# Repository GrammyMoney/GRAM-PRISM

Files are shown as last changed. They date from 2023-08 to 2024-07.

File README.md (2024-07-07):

# GRAM PRI$M

# Introduction 
The **PRI$M** is a modular take on the Prism, originally designed by WunWae. It has the standard pinout for firmwares like HayBox and Pico-Rectangle, and is also compatible with more fleshed-out FGC firmwares like GP2040-CE. The key distinctive features between the original Prism and the PRI$M is the USB-C connectivity, and the modular panels that can be replaced and swapped to change the hand layouts without purchasing a whole new controller. With industrial design from GRAM, PCB designed by Quark.Works, this guide goes over a DIY-friendly approach to building and modifying the PRI$M to suit your needs.

**If you would like to support the developers of this project, consider purchasing parts like buttons, PCBs, USB-C to GCC cables, and official GRAM builds at [GRAMCTRL.COM](https://www.gramctrl.com) rather than a fab house.**

IMG_8768 (1)

Included Files
-
Included in this repo is all the files needed to get started with a PRI$M build:
- **PRI$M Frame .stl files**
- **Aluminum Panel** Gerber files *(5 of 'em!)*
- **PCB Gerbers** for multiple hand layouts and a panelized version for the standard layout

Additional Information
-
If you want more info around GRAM builds, both open source and official builds, please join the [GRAM Digital Controllers Discord](https://discord.gg/6TuHw2r2X4) to ask questions and work with the community! I would love to see people creating new interesting designs, and building upon our initial framework.

Thanks & Acknowledgements
-
There are several people who made this project possible, either directly or indirectly.
- [Quark](https://twitter.com/quark_works), who did the PCB design on this and many other GRAM projects.
- [WunWae](https://twitter.com/WuhnWae), who developed the ergonomics and original Prism design. Thank you for your blessing on this crazy project!
- My life and business partner [BRUISES](https://twitter.com/bruisesxo), who has turned GRAM into what it is today, and had incredible patience with me as I toiled away at my computer late into the night designing this thing.

# Ordering & Customization Guide
While most of these files are universal and can be used at any fab house, **JLCPCB** has become the de-facto standard for DIY box manufacturing. This is due to their hyper-affordable pricing and low minimum order quantity.

Bill of Materials
-
Per GRAM PRI$M, you will need (some files can be made using this repository, but I will link to places to purchase them if you would like to avoid MOQs)
- 1 x PRI$M PCB set *(either panelized, or individual PCBs)*
- 1 x set of PRI$M Aluminum Panels
- 20 x [Kailh Choc V1 switches](https://www.moergo.com/products/kailh-choc-v1-key-switches-red-brown-white-pro-red-20-pack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) (Red, Red Pro, and Whites are all great choices)
- 20 x [PG1350 Hotswap Sockets](https://mkultra.click/kailh-hotswap-sockets)
- 20 x Choc v1 keycaps *(I recommend MBK profile)*
- 1 x GRAM PRI$M Frame
- 8 x [M5x0.8 8mm Low-Profile Socket Head Screws](https://www.mcmaster.com/92855A507)
- 2 x [M2.5x0.45 4mm Button Head Screws](https://www.mcmaster.com/catalog/130/3434/97763A412)
- 1 x [4" JST 6-pin Socket to Socket Reversed cable assembly](https://www.digikey.com/en/products/detail/jst-sales-america-inc/A06SR06SR30K102A/9922193)
- 1 x [4" 14-pin FPC Cable](https://www.digikey.com/en/products/detail/molex/0152670295/4427171)

*Optional*
- USB-C to GCC cable for console/adapter play

Tools Needed
-
This guide assumes a level of knowledge on soldering and computer literacy. General tool requirements are:
- Soldering iron
- Solder
- USB-C to USB-A cable
- 3mm hex key/allen wrench
- Pliers
- Patience :)

The PCB
-
***Note: Since the ordering process of the PRI$M is almost identical to the [SLIM](https://github.com/GrammyMoney/GRAM-SLIM), I have used the ordering guide from the SLIM here. You may need to do more repetitions of these steps depending on which PCB you are printing, and you need to do the panel steps for all 5 aluminum panels.***

The PCB Fabrication files should come in the form of a *Gerber ZIP file* and *bom/cpl files* (usually in Excel spreadsheet formats).

Drag them into the "Upload Gerbers" box at JLCPCB and this page will pop up:



Here you can change the color of the PCB. Green is the fastest and cheapest from JLC, but their black PCBs look *siiiiiick*. The only setting I recommend you change is to check "**Yes**" on *Confirm Production file*. This allows for any mistakes to be ironed out by their engineers.

Towards the bottom of the page, you want to turn on the switch for **PCB ASSEMBLY**.



Make sure you are assembling the *Bottom Side* of the PCB, and make sure to set *Confirm Parts Placement* to "**Yes**". None of the advanced options need to be changed.

Upon confirming your PCB Assembly options, you'll be taken to the Assembly wizard. Clicking next will give you a location to upload the *BOM* and *CPL* files (*CPL* is referred to as *Positions* in the GRAM Slim files). Once you click through, you'll be brought to you BOM list.



This will allow you to modify parts if there's any low stock. There's a line at the bottom for CH1-CH21 with some red text. This is for assembling hotswap sockets, which is not recommended for JLC, as you have to preorder them. when you click **next**, continue by clicking *Do not place*.



The wizard looks intimidating, but good news! Since you're confirming part placement, the JLC engineers will fix any errors. Just go ahead and continue.

There you have it! Your PCB is ready to order. As of the time of this writing, a set of 5 assembled boards costs $56.07 before shipping.

The Panels
-
The process of ordering aluminum panels from JLC is similar to the PCB ordering process, but much simpler. Start by dragging the **GRAM Slim Top** Zip file into the JLC upload window. We want an aluminum PCB, 1.6mm. You can choose either white or black coating (white tends to be glossy, black is matte but a fingerprint magnet). 



Under High-spec Options, make sure to remove order number, or else they'll put an ugly serial number on the panel.

Once you save to cart, you'll see this screen:



Here you can add the **GRAM Slim Bottom** Zip file, and it will copy all your settings from the Top panel. Save to cart, and you're ready to check out with your PCBs!

*Note: JLCPCB cannot transact PCB and 3D printing orders together, so place this order, then move on to 3D printing.*

The Frame
-
The frame file is pretty self explanatory. Just go into JLC's 3D printing section, drop the STL file in, and choose your material. I recommend black Resin, but LEDO 6060 is a great, low cost alternative. The only material I recommend against is the textured Nylon options, as the tolerances between the frame and panels are extremely tight, and the texture could interfere with that. make sure the surface finish is set to *sanded*. 

The website will flag some possible errors (Inverted normals, Multi-shells, Possible noise shells) but if you have not modified the .stl file you are good to go. It is also possible that their support contact you about a risk of deformation given the geometry of the workpiece but it is normal and you should reply to the email that you accept the risks.



Need help building your PRI$M? Feel free to join our [Discord](https://discord.gg/gramctrl) for advice from our lovely open source community!

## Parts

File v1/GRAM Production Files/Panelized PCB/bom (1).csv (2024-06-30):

Designator | Footprint | Quantity | Value | LCSC Part #
C1 | 0402 | 1 | 10uF | C15525
C10, C11, C12, C15, C3, C4, C5, C6, C8, C9 | 0402 | 10 | 100nF | C1525
C13, C14 | 0402 | 2 | 22pF | C1555
C16, C17, C2, C7 | 0402 | 4 | 1uF | C52923
C18 | 0603 | 1 | 4.7u | C19666
CH1, CH10, CH11, CH12, CH13, CH14, CH15, CH16, CH17, CH18, CH19, CH2, CH20, CH3, CH4, CH5, CH6, CH7, CH8, CH9 | Kailh_socket_PG1350 | 20 | choc_SW_HS | C5333465
D1 | D_SOD-123 | 1 | Schottky Diode | C8598
D2 | 0805 | 1 | GREEN | C2297
D3 | D_SOD-323 | 1 | Schottky Diode | C191023
F1 | 1206 | 1 | 500 mA | C151162
J2, J5 | TE_1-84953-4_1x14-1MP_P1.0mm_Horizontal | 2 | FFC Connector | C262348
J3, J8 | JST_SH_SM06B-SRSS-TB_1x06-1MP_P1.00mm_Horizontal | 2 | JST Connector | C160405
J6 | TYPE-C_24P_QCHT | 1 | USB C Connector | C456013
R1, R2 | 0603 | 2 | 27 | C25190
R10, R11 | 0603 | 2 | 5.1k | C23186
R3, R8 | 0402 | 2 | 10k | C25744
R4, R5 | 0402 | 2 | 1k | C11702
R6 | 0603 | 1 | 5.6k | C23189
R7 | 0603 | 1 | 10k | C25804
R9 | 0603 | 1 | 1M | C22935
SW1 | SW_SPST_SKQG_WithStem | 1 | Boot | C318884
U1 | RP2040-QFN-56 | 1 | RP2040 | C2040
U2 | SOIC-8_5.23x5.23mm_P1.27mm | 1 | W25Q128JVS | C97521
U3 | SOT-23 | 1 | XC6206 | C5446
U4, U5 | SOT-23-6 | 2 | USBLC6-2SC6 | C7519
Y1 | Crystal_SMD_3225-4Pin_3.2x2.5mm | 1 | 12MHz | C9002

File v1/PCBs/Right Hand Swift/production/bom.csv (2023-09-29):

Designator | Footprint | Quantity | Value | LCSC Part #
CH10, CH11, CH12, CH13, CH14, CH15, CH16, CH17, CH18, CH20, CH8, CH9 | Kailh_socket_PG1350 | 12 | choc_SW_HS | C5333465
J5 | TE_1-84953-4_1x14-1MP_P1.0mm_Horizontal | 1 | FFC Connector | C376047

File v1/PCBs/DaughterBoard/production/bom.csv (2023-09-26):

Designator | Footprint | Quantity | Value | LCSC Part #
C18 | 0603 | 1 | 4.7u | C19666
D3 | D_SOD-323 | 1 | Schottky Diode | C191023
F1 | 1206 | 1 | 500 mA | C70076
J6 | TYPE-C_24P_QCHT | 1 | USB C Connector | C456013
J8 | JST_SH_SM06B-SRSS-TB_1x06-1MP_P1.00mm_Horizontal | 1 | Conn_01x06 | C160405
R10, R11 | 0603 | 2 | 5.1k | C23186
R9 | 0603 | 1 | 1M | C22935
U4, U5 | SOT-23-6 | 2 | USBLC6-2SC6 | C7519

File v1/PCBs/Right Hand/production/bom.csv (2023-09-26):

Designator | Footprint | Quantity | Value | LCSC Part #
CH10, CH11, CH12, CH13, CH14, CH15, CH16, CH17, CH18, CH19, CH20, CH8, CH9 | SW_choc_v1_HS_1u | 13 | choc_SW_HS | C5333465
J5 | TE_1-84953-4_1x14-1MP_P1.0mm_Horizontal | 1 | FFC Connector | C376047

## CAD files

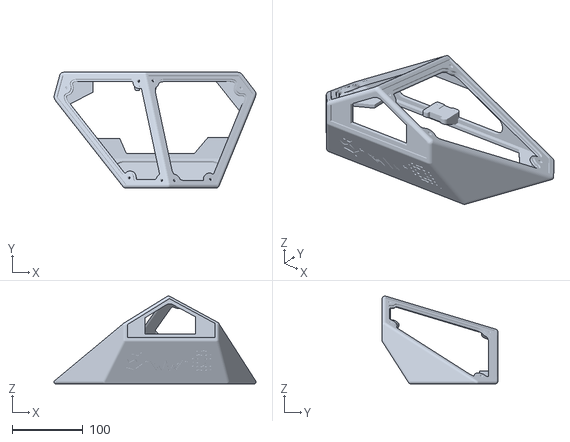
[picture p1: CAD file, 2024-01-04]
v1/GRAM Production Files/gram prism v1 frame.stl
285.0 x 163.6 x 124.0

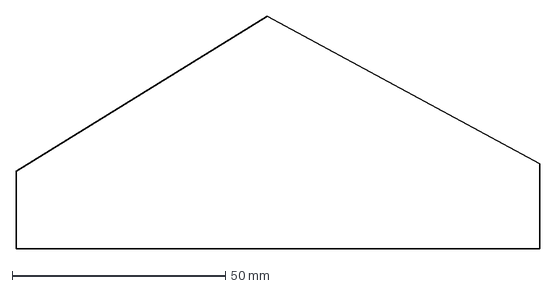
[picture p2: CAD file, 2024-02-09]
v1/outlines/smallest back.dxf
122.6 x 54.6 mm

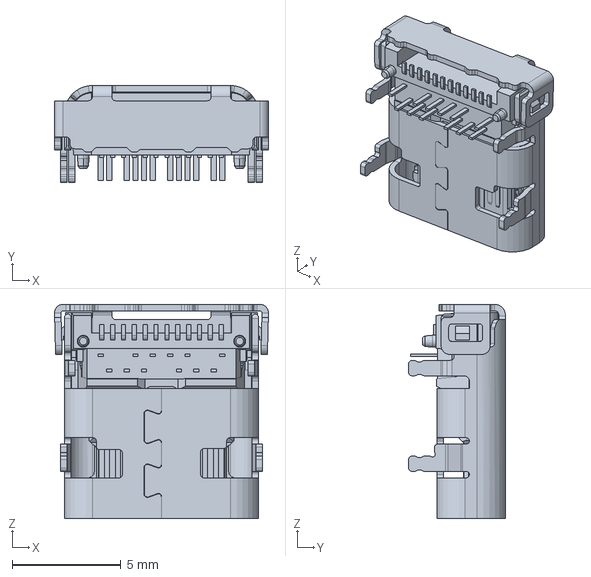
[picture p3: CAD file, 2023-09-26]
v1/PCBs/DaughterBoard/TYPE-C_24P_QCHT.stp
9.85 x 4.46 x 9.87 mm

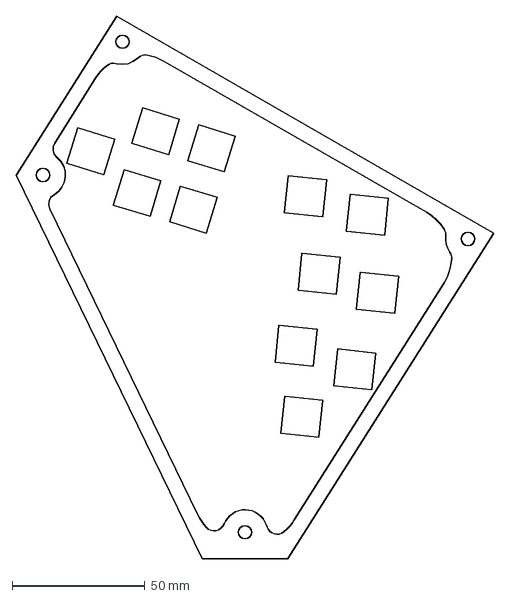
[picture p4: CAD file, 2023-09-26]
v1/user drawings/right pcb user profile (swift style) fixed.dxf
179.8 x 204.4 mm

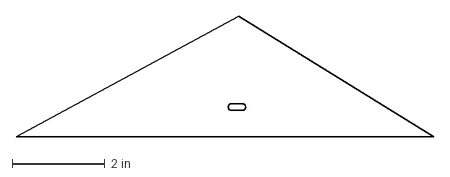
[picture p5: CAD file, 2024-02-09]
v1/outlines/front with port.dxf
8.98 x 2.59 in

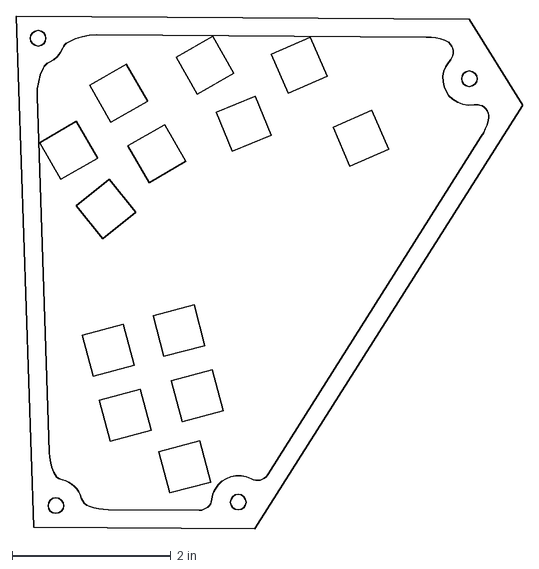
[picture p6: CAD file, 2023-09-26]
v1/user drawings/right_pcb_user_profile_traditional_fixed.dxf
6.37 x 6.45 in

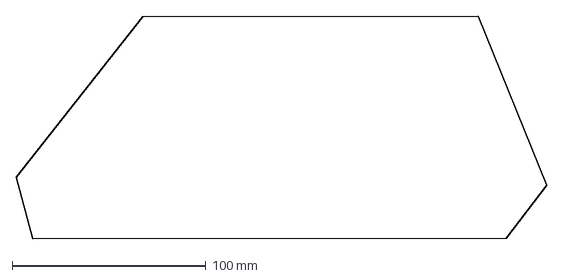
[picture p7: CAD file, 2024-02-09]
v1/outlines/bottom.dxf
273.9 x 114.6 mm

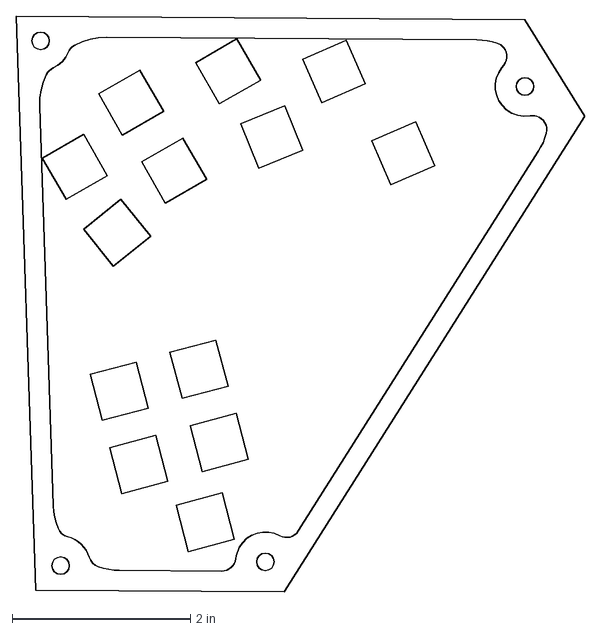
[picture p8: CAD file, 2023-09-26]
v1/user drawings/right pcb user profile (traditional).dxf
6.37 x 6.45 in

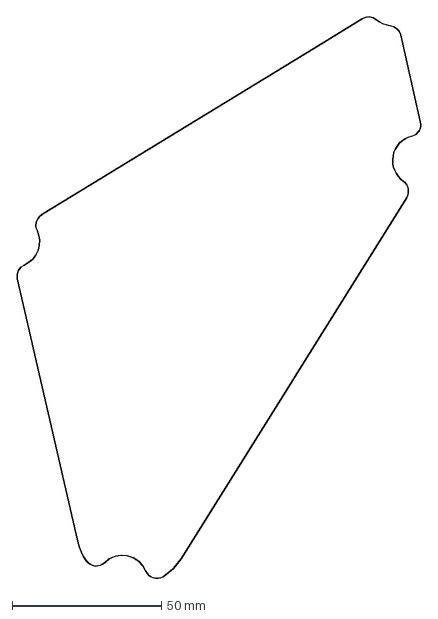
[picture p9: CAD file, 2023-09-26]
v1/outlines/left PCB fixed.dxf
135.8 x 188.4 mm

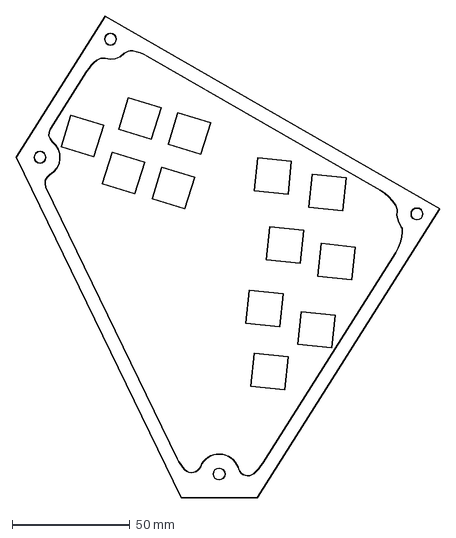
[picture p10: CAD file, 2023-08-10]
v1/user drawings/right pcb user profile (swift style).dxf
179.8 x 204.4 mm

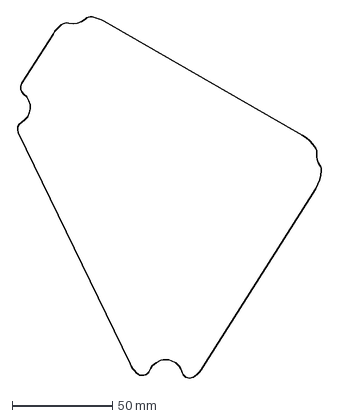
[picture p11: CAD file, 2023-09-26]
v1/outlines/right PCB fixed.dxf
152.4 x 180.9 mm

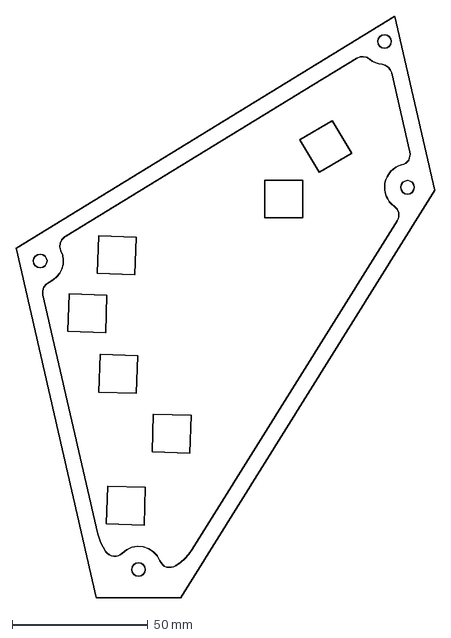
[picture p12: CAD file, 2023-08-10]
v1/user drawings/left pcb user profile.dxf
154.0 x 213.7 mm

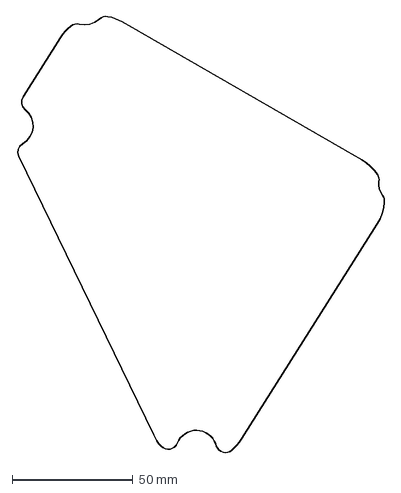
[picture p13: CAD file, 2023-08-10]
v1/outlines/right PCB.dxf
152.4 x 180.9 mm

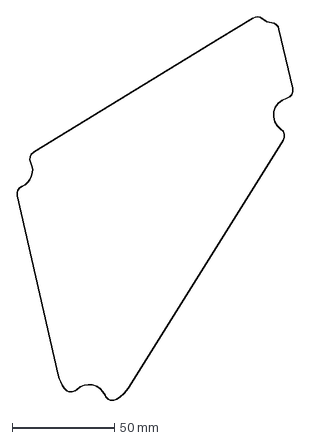
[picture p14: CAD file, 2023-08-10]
v1/outlines/left PCB.dxf
135.8 x 188.4 mm

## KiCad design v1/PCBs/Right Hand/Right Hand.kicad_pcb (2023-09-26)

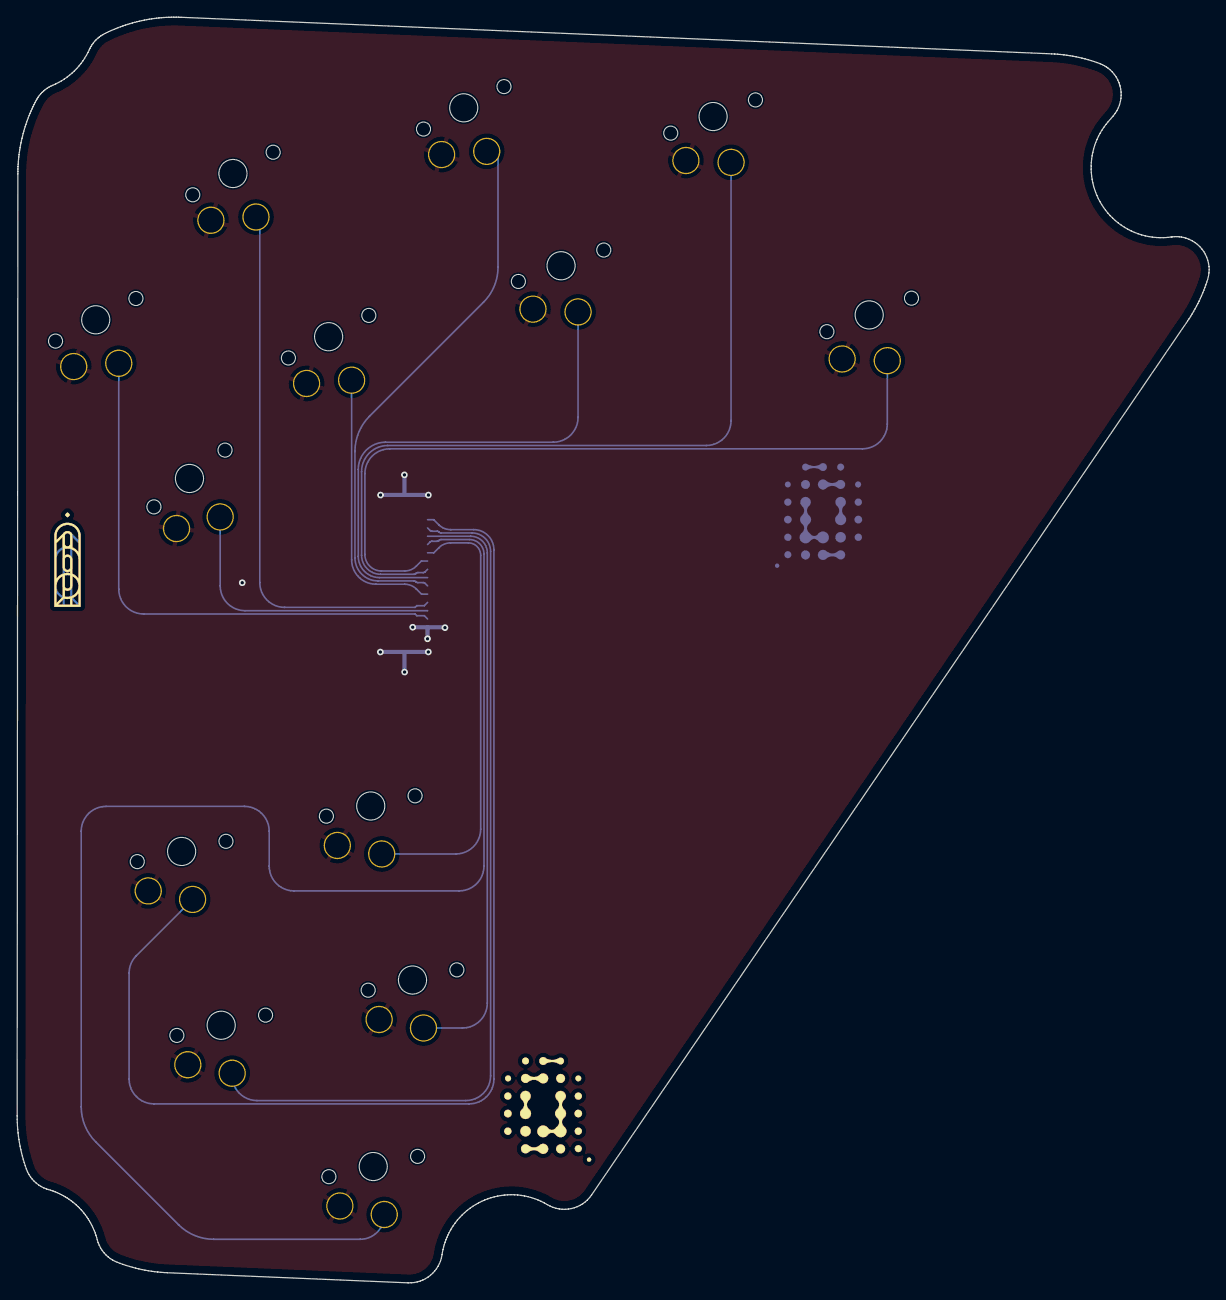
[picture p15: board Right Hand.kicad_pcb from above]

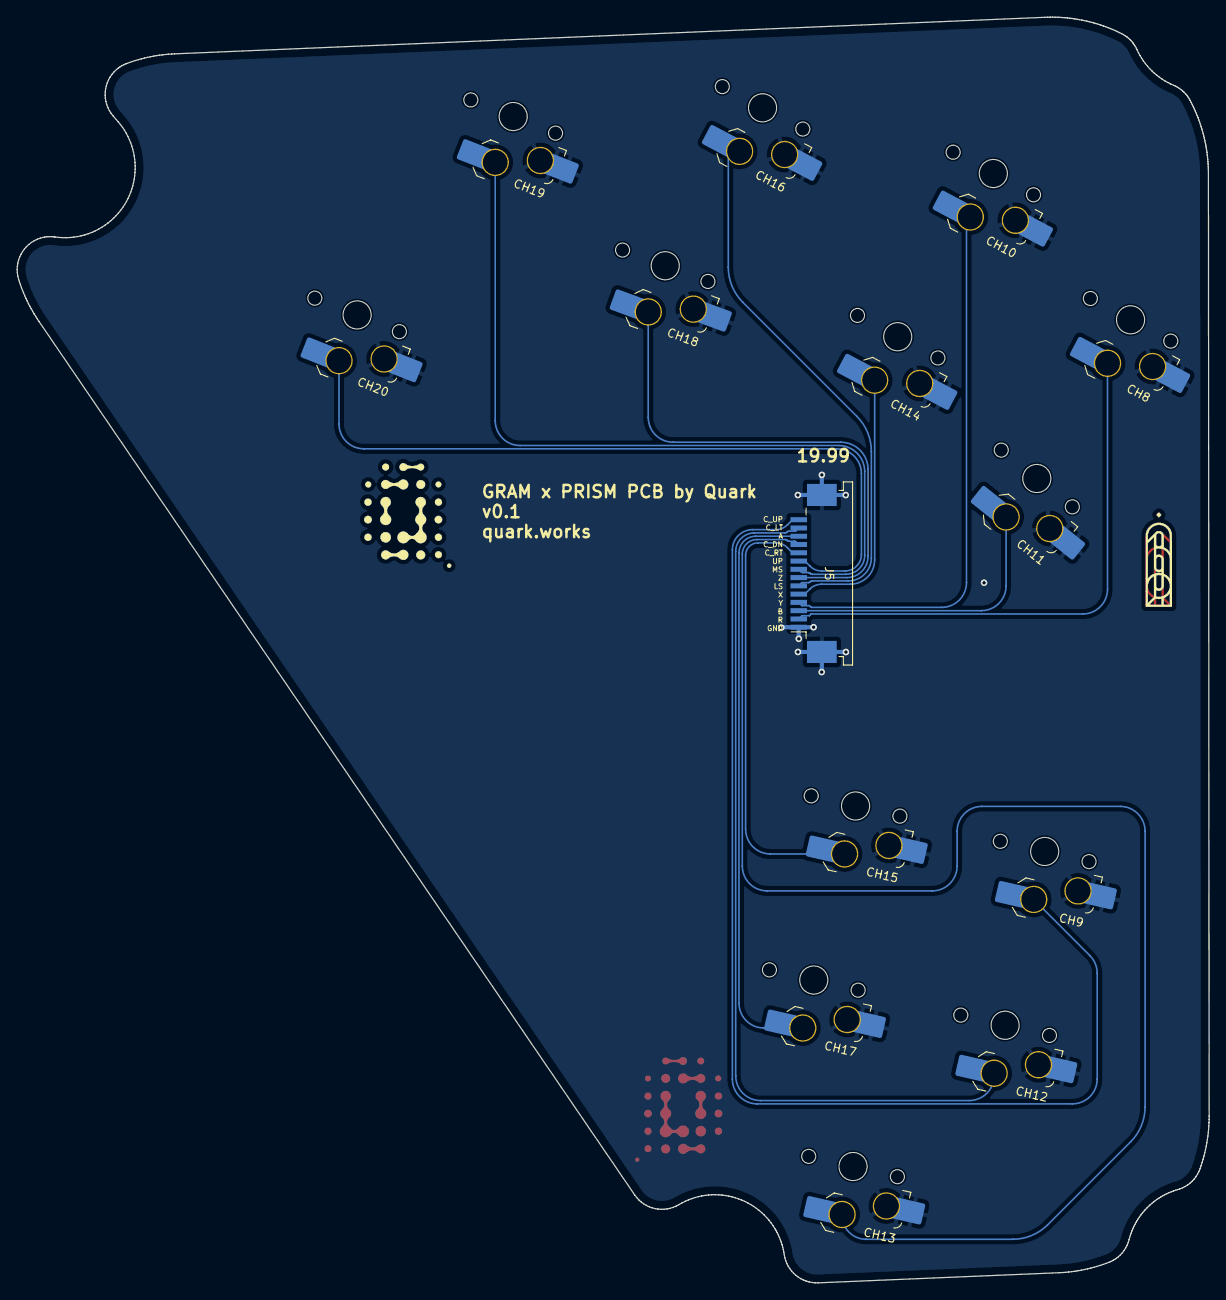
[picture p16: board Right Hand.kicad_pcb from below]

Board: 2 copper layers, 144.1 x 153.0 mm, 18 parts (16 on the bottom side), 14 nets.

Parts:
CH8, CH9, CH10, CH11, CH12, CH13, CH14, CH15, CH16, CH17, CH18, CH19, CH20: choc_SW_HS; SW_choc_v1_HS_1u
H5, H6: qw-logo; qw new logo silk + copper md
H7, H8: 19.99 logo; 1999 logo md
J5: FFC Connector; TE_1-84953-4_1x14-1MP_P1.0mm_Horizontal

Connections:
A: CH17.2, J5.12
B: CH11.2, J5.3
C_DN: CH13.2, J5.11
C_LT: CH12.2, J5.13
C_RT: CH15.2, J5.10
C_UP: CH9.2, J5.14
GND: CH8.1, CH9.1, CH10.1, CH11.1, CH12.1, CH13.1, CH14.1, CH15.1, CH16.1, CH17.1, CH18.1, CH19.1, CH20.1, J5.1, J5.MP (MountPin)
LS: CH16.2, J5.6
MS: CH19.2, J5.8
R: CH8.2, J5.2
UP: CH20.2, J5.9
X: CH14.2, J5.5
Y: CH10.2, J5.4
Z: CH18.2, J5.7

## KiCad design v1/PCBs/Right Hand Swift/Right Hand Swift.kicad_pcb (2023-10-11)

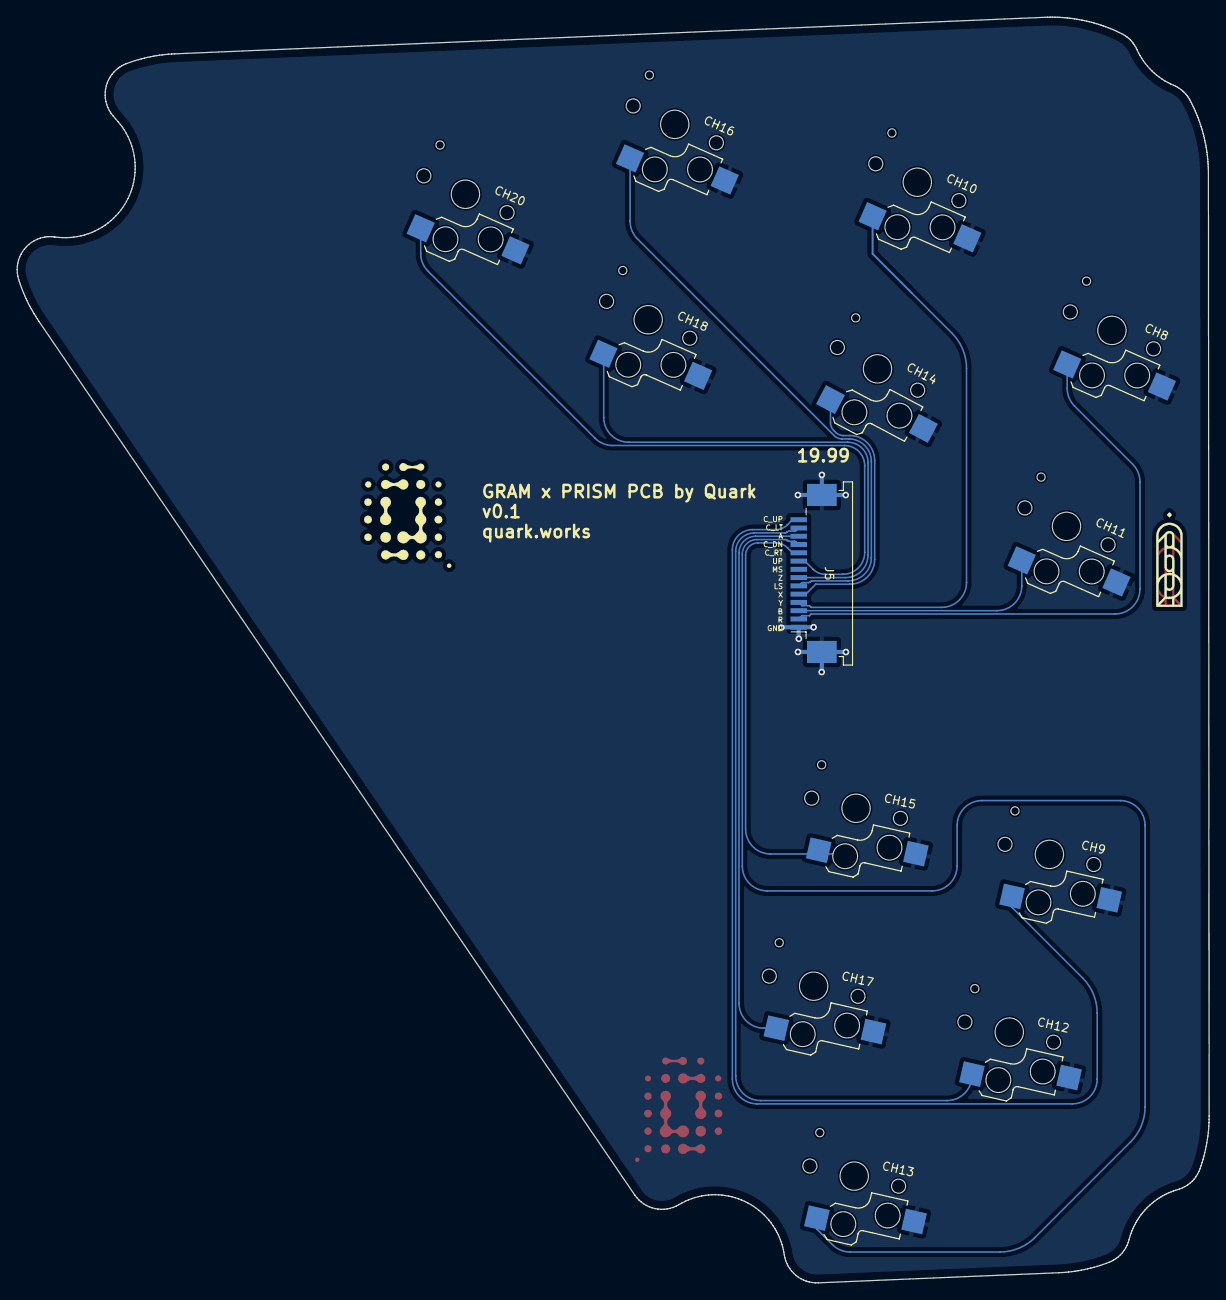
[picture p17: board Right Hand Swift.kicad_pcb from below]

Board: 2 copper layers, 144.1 x 153.0 mm, 17 parts (3 on the bottom side), 13 nets.

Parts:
CH8, CH9, CH10, CH11, CH12, CH13, CH14, CH15, CH16, CH17, CH18, CH20: choc_SW_HS; Kailh_socket_PG1350
H5, H6: qw-logo; qw new logo silk + copper md
H7, H8: 19.99 logo; 1999 logo md
J5: FFC Connector; TE_1-84953-4_1x14-1MP_P1.0mm_Horizontal

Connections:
A: CH17.1, J5.12
B: CH11.1, J5.3
C_DN: CH13.1, J5.11
C_LT: CH12.1, J5.13
C_RT: CH15.1, J5.10
C_UP: CH9.1, J5.14
GND: CH8.2, CH9.2, CH10.2, CH11.2, CH12.2, CH13.2, CH14.2, CH15.2, CH16.2, CH17.2, CH18.2, CH20.2, J5.1, J5.MP (MountPin)
LS: CH16.1, J5.6
R: CH8.1, J5.2
UP: CH20.1, J5.9
X: CH14.1, J5.5
Y: CH10.1, J5.4
Z: CH18.1, J5.7

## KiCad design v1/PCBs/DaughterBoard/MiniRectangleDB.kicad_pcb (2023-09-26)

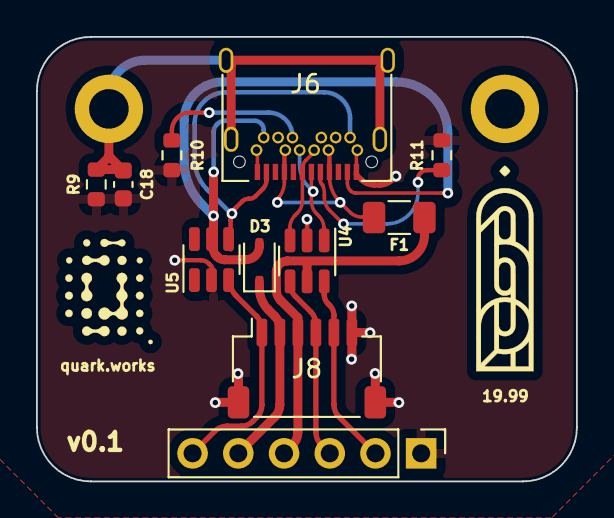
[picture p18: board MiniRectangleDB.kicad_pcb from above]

Board: 2 copper layers, 30.0 x 24.7 mm, 15 parts (0 on the bottom side), 14 nets.

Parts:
C18: 4.7u; C_0603_1608Metric
D3: Schottky Diode; D_SOD-323
F1: 500 mA; Fuse_1206_3216Metric
H9: MountingHole_Pad; MountingHole_2.2mm_M2_DIN965_Pad
H10: MountingHole; MountingHole_2.2mm_M2_DIN965_Pad
H11: qw logo; qw new logo silk + copper sm
H12: 1999 logo; 1999 logo md
J6: USB C Connector; TYPE-C_24P_QCHT
J7: Conn_01x06; PinHeader_1x06_P2.54mm_Vertical
J8: Conn_01x06; JST_SH_SM06B-SRSS-TB_1x06-1MP_P1.00mm_Horizontal
R9: 1M; R_0603_1608Metric
R10, R11: 5.1k; R_0603_1608Metric
U4, U5: USBLC6-2SC6; SOT-23-6

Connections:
3vCable: D3.2 (A), J6.A2 (TX1+), J6.B2 (TX2+), U5.5 (VBUS)
3vDiode: D3.1 (K), J7.5, J8.2
+5V: F1.2, J7.4, J8.3, U4.5 (VBUS)
D+: J7.2, J8.5, U4.6 (I/O1)
D-: J7.3, J8.4, U4.4 (I/O2)
DATA: J7.6, J8.1, U5.3 (I/O2)
DATABUS: J6.A11 (RX2+), J6.B11 (RX1+), U5.4 (I/O2)
DBUS+: J6.A6 (D+), J6.B6 (D+), U4.1 (I/O1)
DBUS-: J6.A7 (D-), J6.B7 (D-), U4.3 (I/O2)
GND: C18.2, J6.A1 (GND), J6.A12 (GND), J6.B1 (GND), J6.B12 (GND), J7.1, J8.6, R9.1, R10.1, R11.2, U4.2 (GND), U5.2 (GND)
unnamed: F1.1, J6.A4 (VBUS), J6.A9 (VBUS), J6.B4 (VBUS), J6.B9 (VBUS)
unnamed: J6.A5 (CC1), R11.1
unnamed: J6.B5 (CC2), R10.2
unnamed: C18.1, H9.1, J6.S1 (SHIELD), R9.2

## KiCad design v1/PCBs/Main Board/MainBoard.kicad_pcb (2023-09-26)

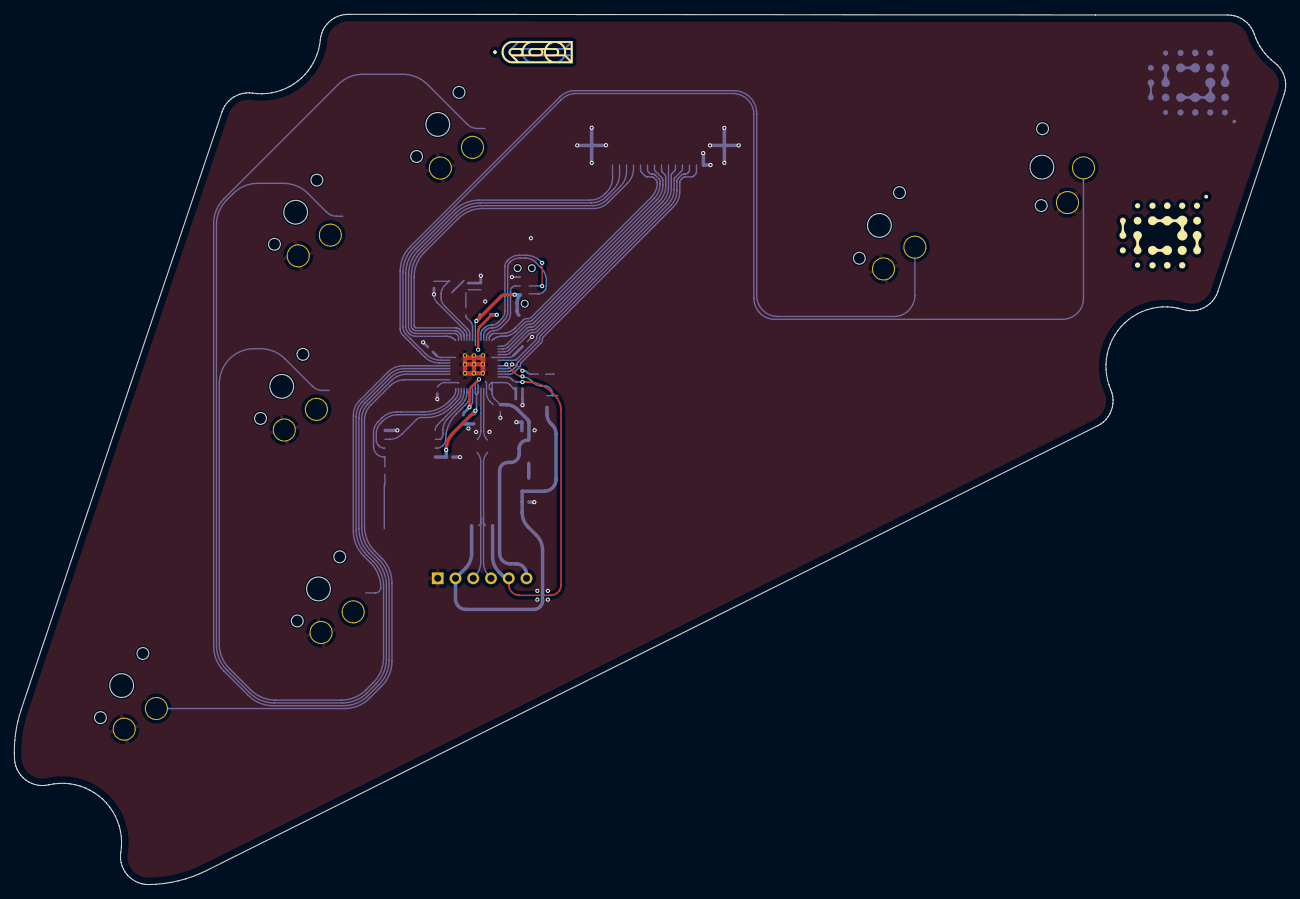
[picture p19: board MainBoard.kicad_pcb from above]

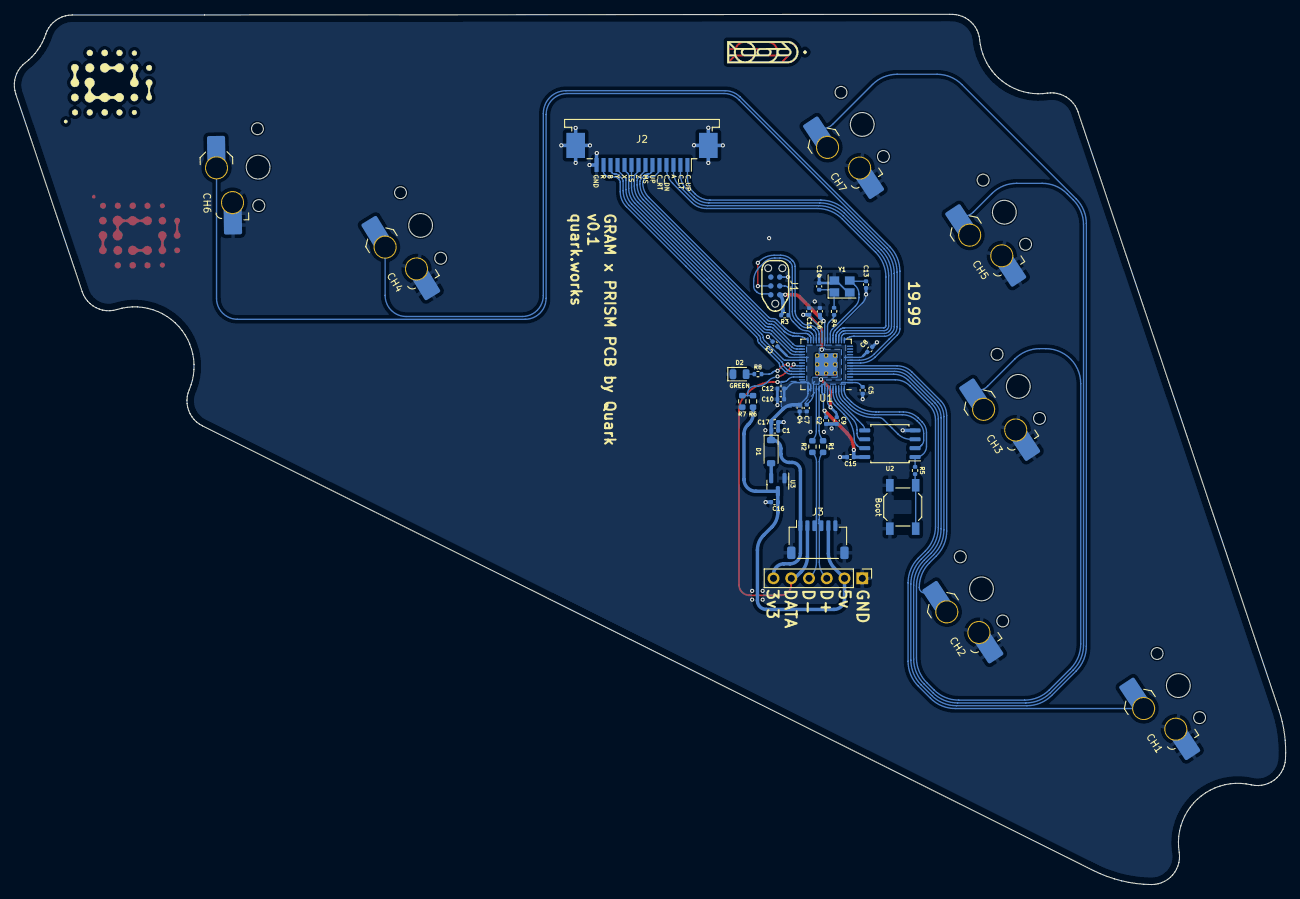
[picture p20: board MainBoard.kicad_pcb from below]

Board: 2 copper layers, 181.9 x 124.5 mm, 47 parts (45 on the bottom side), 46 nets.

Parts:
C1: 10uF; C_0402_1005Metric
C2, C7, C16, C17: 1uF; C_0402_1005Metric
C3, C4, C5, C6, C8, C9, C10, C11, C12, C15: 100nF; C_0402_1005Metric
C13, C14: 22pF; C_0402_1005Metric
CH1, CH2, CH3, CH4, CH5, CH6, CH7: choc_SW_HS; SW_choc_v1_HS_1u
D1: Schottky Diode; D_SOD-123
D2: GREEN; LED_0805_2012Metric
H1, H2: qw-logo; qw new logo silk + copper md
H3, H4: 19.99 logo; 1999 logo md
J1: JTAG_TC2030; CON_TC2030_outlined
J2: FFC Connector; TE_1-84953-4_1x14-1MP_P1.0mm_Horizontal
J3: JST Connector; JST_SH_SM06B-SRSS-TB_1x06-1MP_P1.00mm_Horizontal
J4: DuPont Connector; PinHeader_1x06_P2.54mm_Vertical
R1, R2: 27; R_0603_1608Metric
R3, R8: 10k; R_0402_1005Metric
R4, R5: 1k; R_0402_1005Metric
R6: 5.6k; R_0603_1608Metric
R7: 10k; R_0603_1608Metric
SW1: Boot; SW_SPST_SKQG_WithStem
U1: RP2040; RP2040-QFN-56
U2: W25Q128JVS; SOIC-8_5.23x5.23mm_P1.27mm
U3: XC6206; SOT-23
Y1: 12MHz; Crystal_SMD_3225-4Pin_3.2x2.5mm

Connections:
+1V1: C7.1, C9.1, C11.1, U1.23 (DVDD), U1.45 (VREG_VOUT), U1.50 (DVDD)
+3V3: C1.1, C2.1, C3.1, C4.1, C5.1, C6.1, C8.1, C10.1, C12.1, C15.1, C17.2, D1.1 (K), J1.1 (VCC), J3.1, J4.6, R3.1, U1.1 (IOVDD), U1.10 (IOVDD), U1.22 (IOVDD), U1.33 (IOVDD), U1.42 (IOVDD), U1.43 (ADC_AVDD), U1.44 (VREG_VIN), U1.48 (USB_VDD), U1.49 (IOVDD), U2.8 (VCC)
+5V: C16.2, J3.5, J4.2, R6.1, U3.3 (VI)
/D_+: R1.2, U1.47 (D+)
/D_-: R2.2, U1.46 (D-)
/XTAL_O: C14.2, R4.1, Y1.1
/~USB_BOOT: R5.1, SW1.2
A: J2.3, U1.17 (GPIO14)
B: J2.12, U1.38 (GPIO26/ADC0)
CS: R5.2, U1.56 (QSPI_SS_N), U2.1 (~CS)
C_DN: J2.4, U1.18 (GPIO15)
C_LT: J2.2, U1.16 (GPIO13)
C_RT: J2.5, U1.27 (GPIO16)
C_UP: J2.1, U1.15 (GPIO12)
D+: J3.4, J4.3, R1.1
D-: J3.3, J4.4, R2.1
DATA: J3.2, J4.5, U1.40 (GPIO28/ADC2)
DOWN: CH5.2, U1.5 (GPIO3)
GND: C1.2, C2.2, C3.2, C4.2, C5.2, C6.2, C7.2, C8.2, C9.2, C10.2, C11.2, C12.2, C13.1, C14.1, C15.2, C16.1, C17.1, CH1.1, CH2.1, CH3.1, CH4.1, CH5.1, CH6.1, CH7.1, D2.1 (K), J1.5 (GND), J2.14, J2.MP (MountPin), J3.6, J3.MP (MountPin), J4.1, R7.2, SW1.1, U1.19 (TESTEN), U1.57 (GND), U2.4 (GND), U3.1 (GND), Y1.2, Y1.4
L: CH2.2, U1.7 (GPIO5)
LEFT: CH3.2, U1.6 (GPIO4)
LS: J2.9, U1.31 (GPIO20)
M1: CH4.2, U1.8 (GPIO6)
M2: CH6.2, U1.9 (GPIO7)
MS: J2.7, U1.29 (GPIO18)
unnamed: D1.2 (A), U3.2 (VO)
unnamed: D2.2 (A), R8.2
PICO_LED: R8.1, U1.37 (GPIO25)
QSPI_CLK: U1.52 (QSPI_SCLK), U2.6 (CLK)
R: J2.13, U1.39 (GPIO27/ADC1)
RIGHT: CH7.2, U1.4 (GPIO2)
SD0: U1.53 (QSPI_SD0), U2.5 (DI(IO0))
SD1: U1.55 (QSPI_SD1), U2.2 (DO(IO1))
SD2: U1.54 (QSPI_SD2), U2.3 (IO2)
SD3: U1.51 (QSPI_SD3), U2.7 (IO3)
START: CH1.2, U1.2 (GPIO0)
SWCLK: J1.4 (SWCLK), U1.24 (SWCLK)
SWD: J1.2 (SWDIO), U1.25 (SWDIO)
UP: J2.6, U1.28 (GPIO17)
VBUS_SENSE: R6.2, R7.1, U1.36 (GPIO24)
X: J2.10, U1.32 (GPIO21)
XTAL_IN: C13.2, U1.20 (XTAL_IN), Y1.3
XTAL_OUT: R4.2, U1.21 (XTAL_OUT)
Y: J2.11, U1.34 (GPIO22)
Z: J2.8, U1.30 (GPIO19)
~RESET: J1.3 (~RST), R3.2, U1.26 (~RUN)

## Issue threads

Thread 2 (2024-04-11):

Add LICENSE file

Soundtoxin, 2024-04-11:
It doesn't look like there's a license for this repo yet, which would mean it defaults to All Rights Reserved. I saw people talking about this like it was "open source", which it wouldn't be without a license. Maybe you just forgot to add one.
https://choosealicense.com/

Open-Frame1 and HayBox are both GPL-3.0, for the record.

GrammyMoney, 2024-07-07:
Fixed, thank you for pointing this out!

Closed 2024-07-07.

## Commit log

2023-09-26 First panelized revision
    [Buttons.kicad_sch, MainBoard.kicad_pcb, MainBoard.kicad_sch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]
2023-09-26 Added individual production files
    [MainBoard.kicad_pcb, MainBoard.kicad_sch, MiniRectangleDB.kicad_pcb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]
2023-09-26 Added right hand swift and production files
    [Right Hand Swift.kicad_pcb, Right Hand Swift.kicad_sch, bom.csv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]
2023-09-28 Added finalized production files for frame and aluminum panels
    [GRAM x PRISM REAL v0.1.step, frame 0.1.stl, right pcb user profile (traditional).dxf]
2023-09-29 Adjusted choc to the preferred footprint
    [Panelized Board.kicad_sch, bom.csv, positions.csv]
2023-09-29 Adjusted Swift right side to the preferred footprint
    [Right Hand Swift.kicad_pcb, Right Hand Swift.kicad_sch, bom.csv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]
2023-10-11 Adjusted daughterboard pinout and drill hole error on right hand
    [Panelized Board.kicad_sch, Right Hand Swift.kicad_pcb]
2023-10-18 expanded holes
2024-01-04 Cleaned up for public release
    [Buttons.kicad_sch, MainBoard.kicad_pcb, MainBoard.kicad_sch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]
2024-02-08 [Documentation] Adding a note about the possible warnings that can happen with JLCPCB for 3D printing of the frame
2024-02-09 added extra panel DXFs
    [bottom.dxf, front with port.dxf, smallest back.dxf]
2024-06-22 Updated JST connector orientation
2024-06-30 Updated FFC connector and Fuse part number
    [bom (1).csv, bom.csv]
2024-07-01 Adjusted hot swap sockets positioning
    [positions (1).csv, positions.csv]
2024-07-07 Added M2.5 Screws (thanks biz_fish!)
